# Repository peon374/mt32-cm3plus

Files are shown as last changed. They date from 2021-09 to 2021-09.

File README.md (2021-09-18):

# mt32-cm3plus
This is a CM3+ version of the MT32Pi hardware. All layout is done in Kicad and I will create release files with everything needed to get a run of boards done and half assembled with jlcpcb.

This project is a hardware implementation designed to work with [MT32-Pi](https://github.com/dwhinham/mt32-pi)

_THIS IS A WORK IN PROGRESS AND ISN'T COMPLETE_

You should not build this till there are is a working release. The convention I will be using is to call something a release candidate (RC) till I know everything I have added works and I have reasonable documentation. If you do not see reasonable documentation, either contribute doco, ideas or bugs you can see in what I have done. The plan is to have everything that can be populated out of JLCPCB basic parts on the underside so that a lot of the fiddly bits are already done. The SODIMM connector for the CM3+ is not simple if you don't have a good iron and good flux. Both can be found on Aliexpress with a bit of research but flux is more of a gamble.

I plan to continue improving the device, so if you have any ideas put them in.

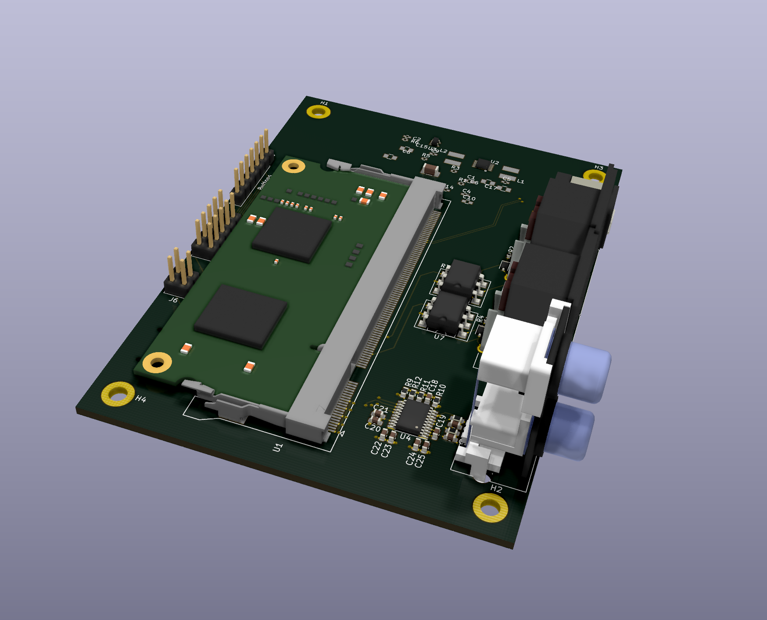
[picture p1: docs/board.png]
Board


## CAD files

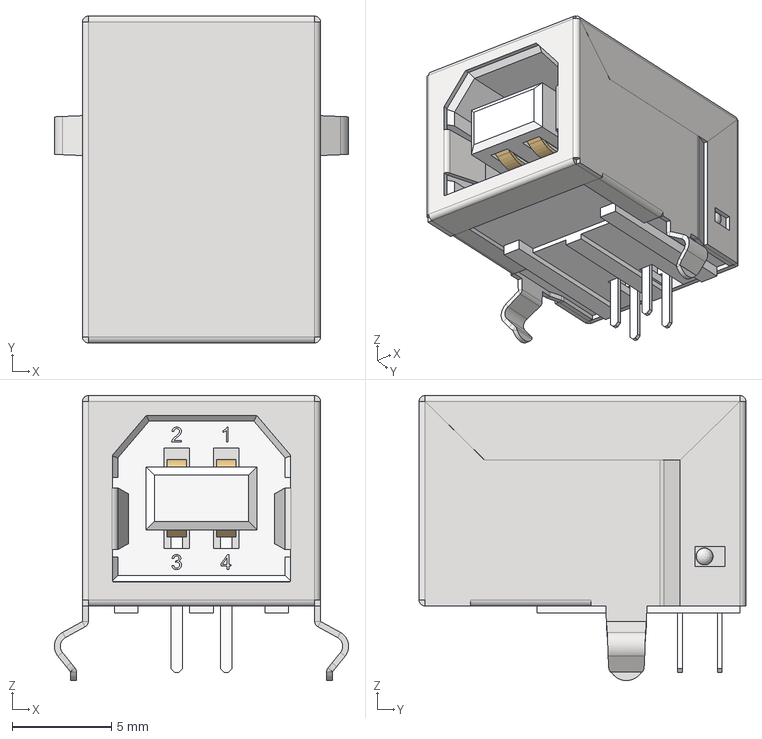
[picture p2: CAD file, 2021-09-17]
hardware/step/USB 2.0 Type B Connector Right Angle (Würth 61400416121).stp
14.8 x 16.5 x 14.4 mm

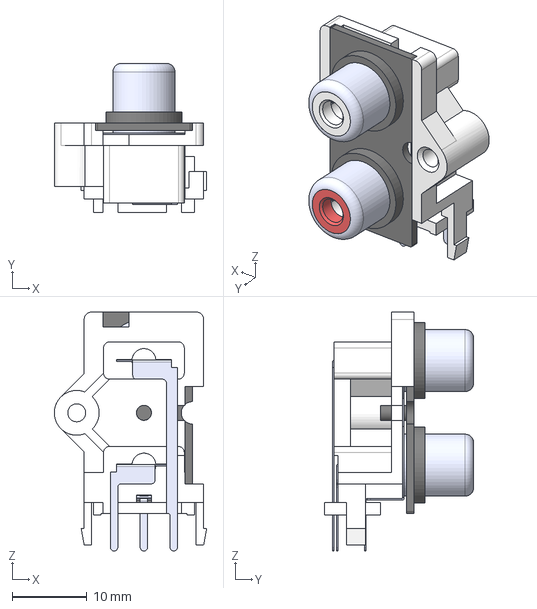
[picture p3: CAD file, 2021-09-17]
hardware/step/RS-209.step
20.4 x 20.0 x 32.0 mm

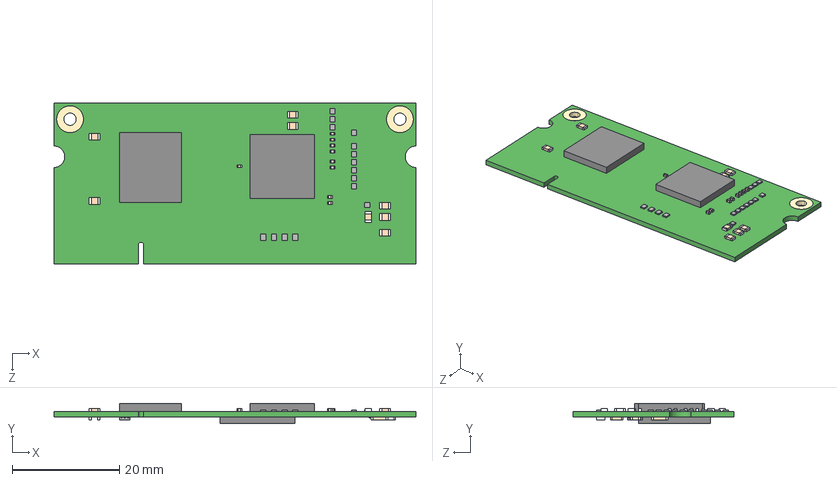
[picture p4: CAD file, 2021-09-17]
hardware/step/RASPBERRYPI-CM3--3DModel-STEP-56544.STEP
67.6 x 3.80 x 30.0 mm

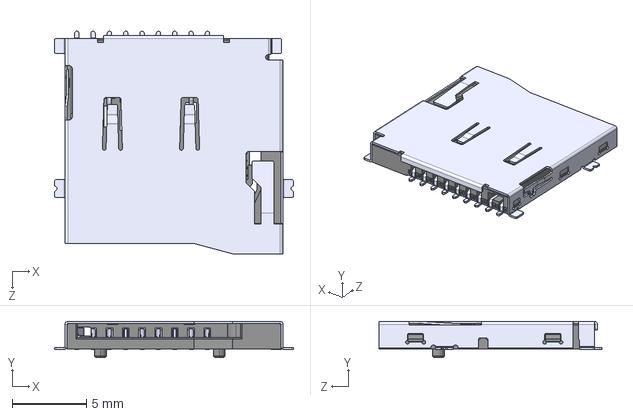
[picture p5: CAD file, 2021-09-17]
hardware/step/ST-TF-003A--3DModel-STEP-56544.STEP
16.1 x 2.45 x 15.0 mm

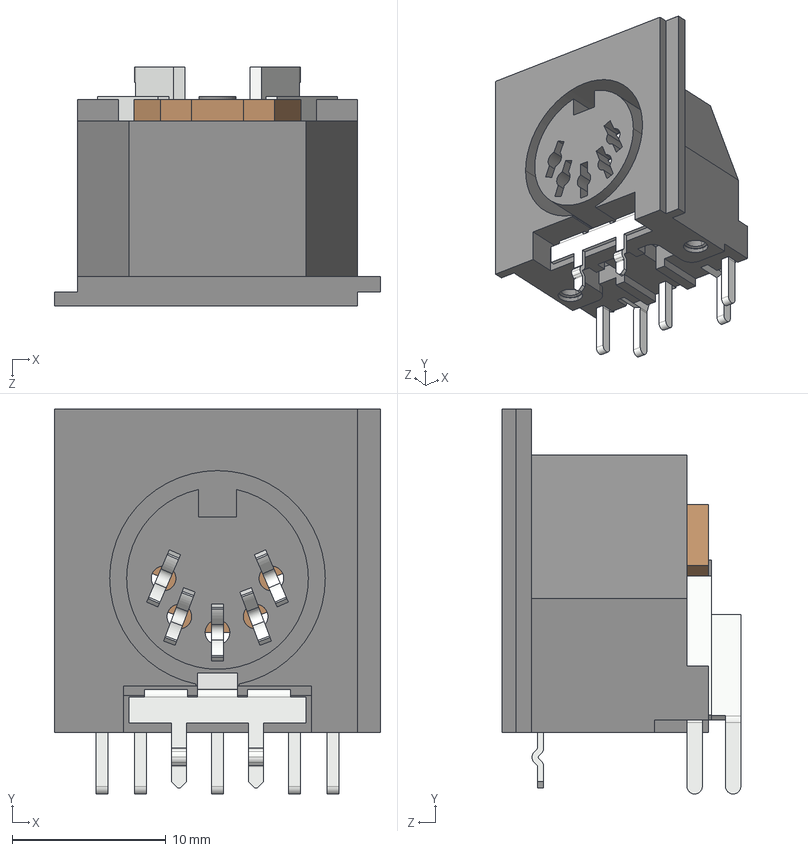
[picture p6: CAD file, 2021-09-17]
hardware/step/DIN5_PCB_DELTRON_671-0500.STEP
21.2 x 25.0 x 15.5 mm
DIN5_PCB_DELTRON_BODY
DIN5_PCB_DELTRON_PIN2
DIN5_PCB_DELTRON_PIN5
DIN5_PCB_DELTRON_PIN3
DIN5_PCB_DELTRON_PIN4
DIN5_PCB_DELTRON_PIN1
DIN5_PCB_DELTRON_FIX
DIN5_PCB_DELTRON_SHIELD

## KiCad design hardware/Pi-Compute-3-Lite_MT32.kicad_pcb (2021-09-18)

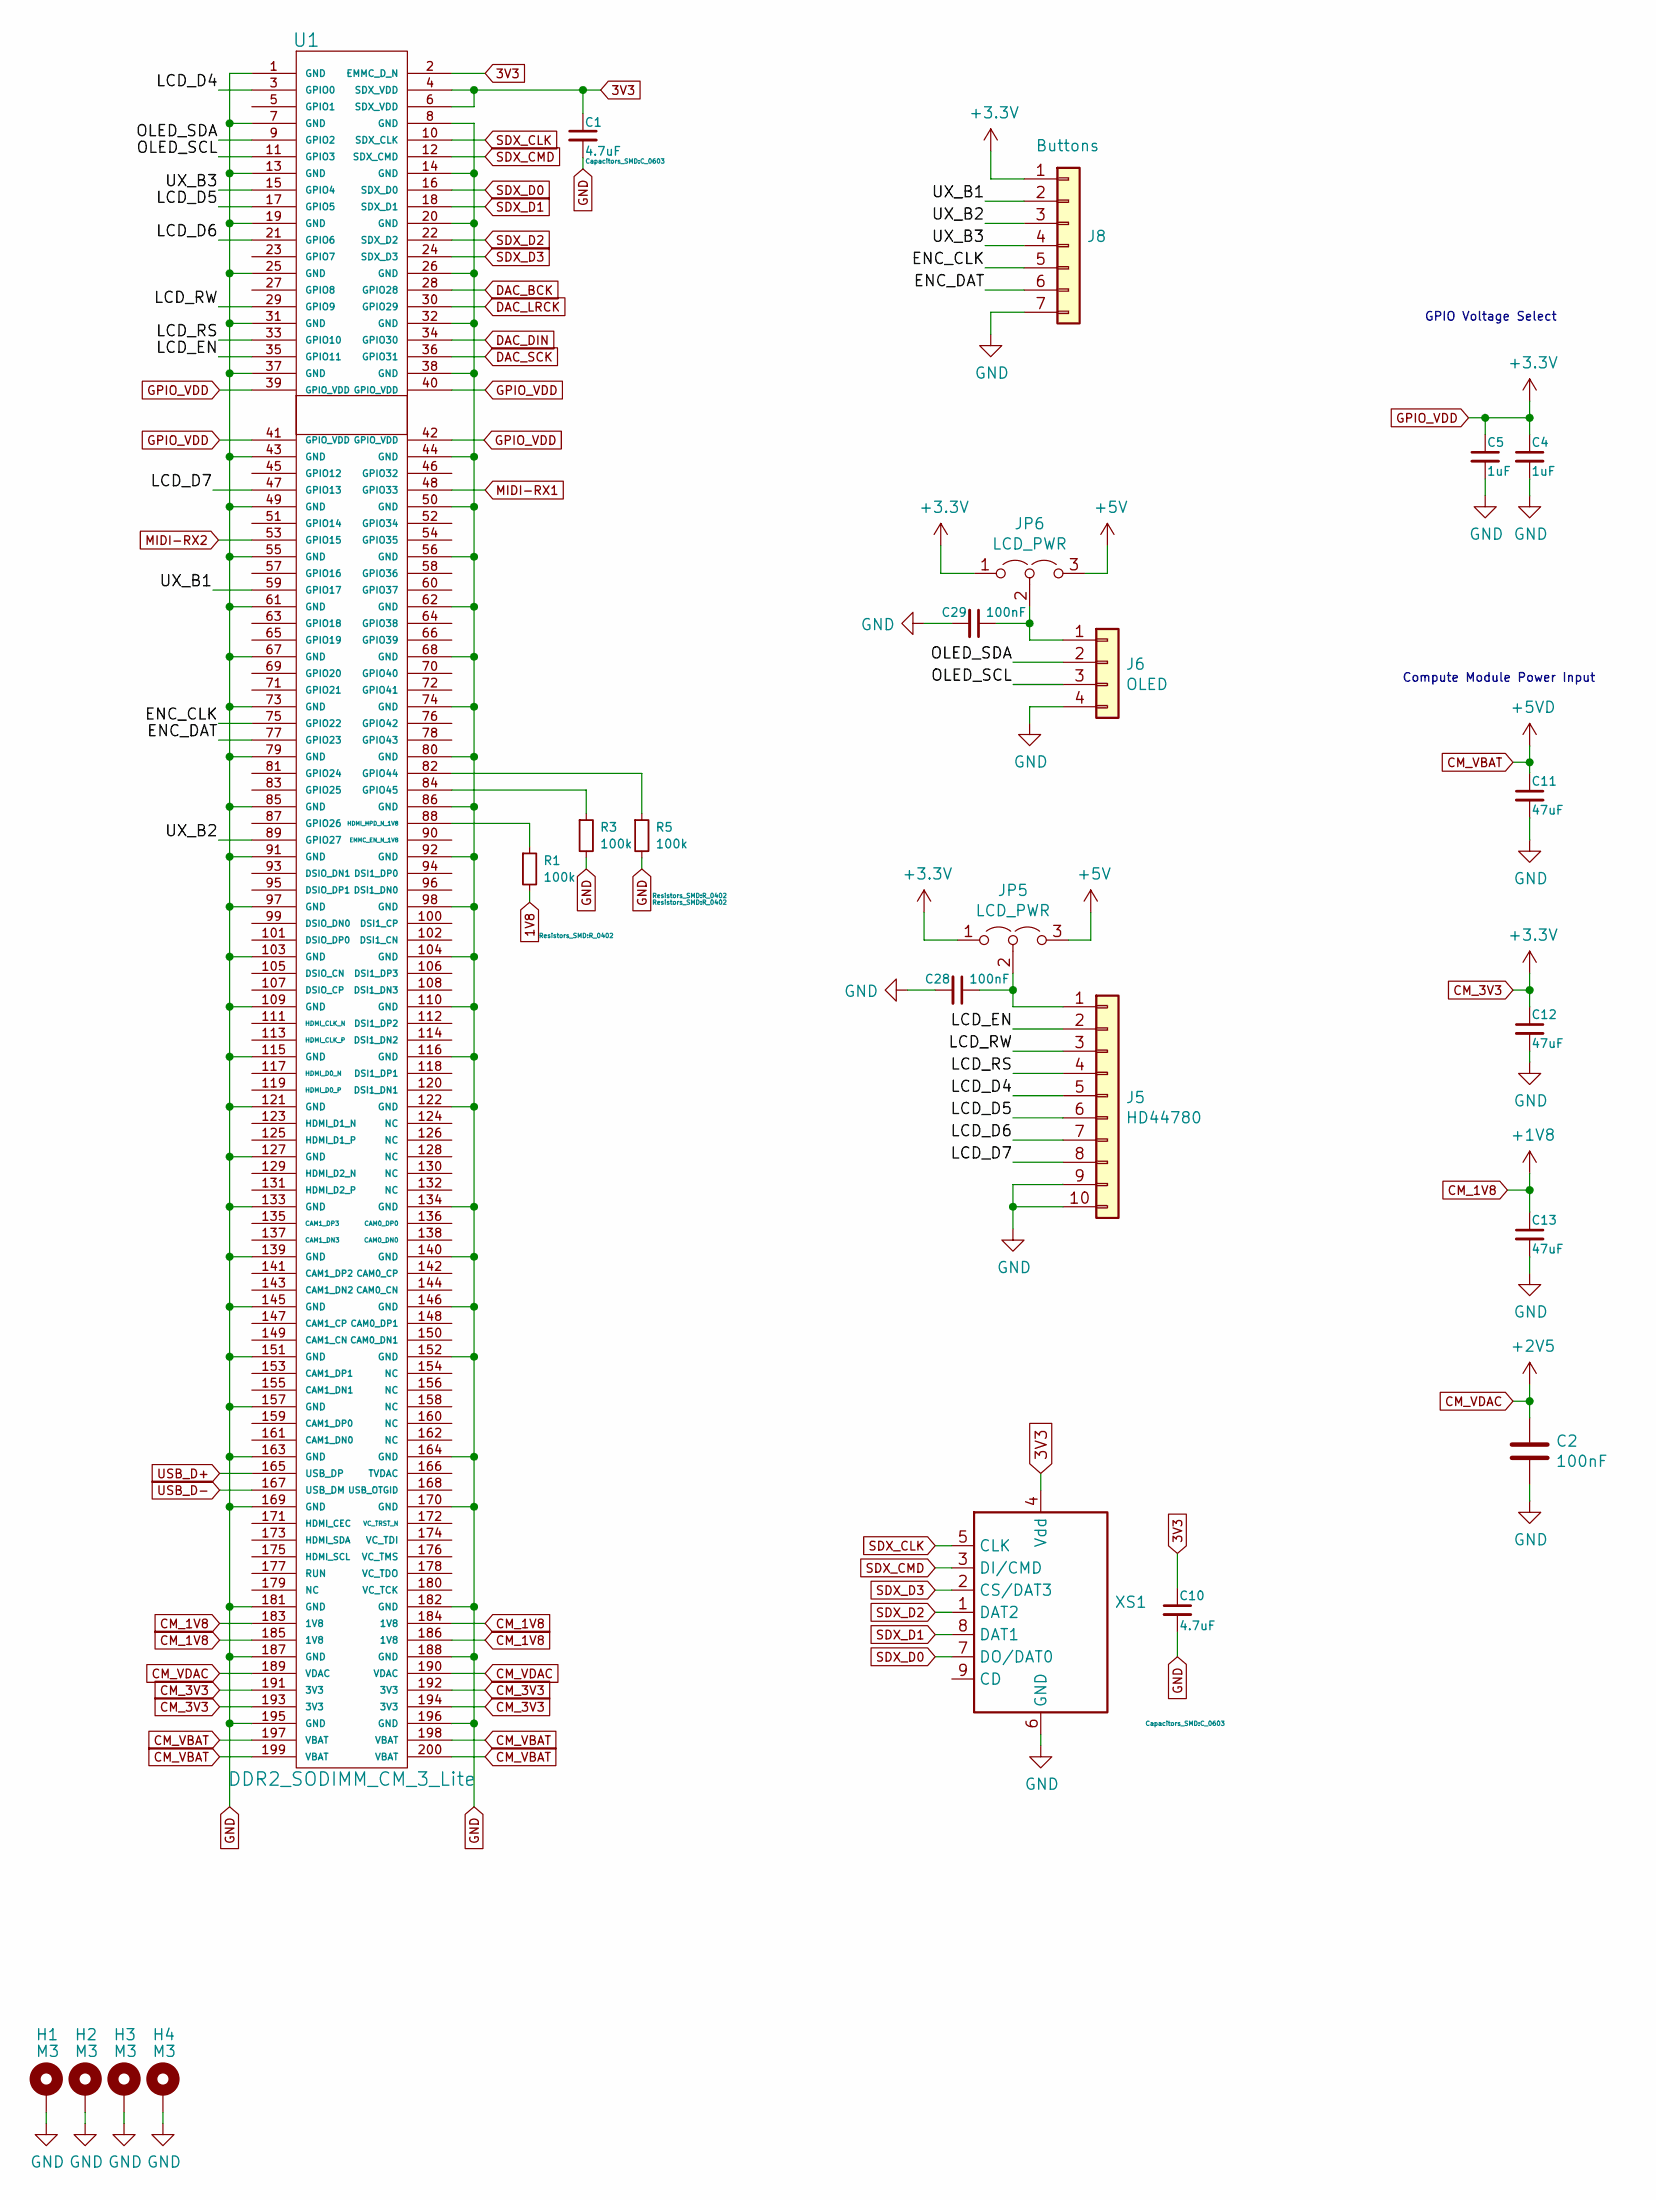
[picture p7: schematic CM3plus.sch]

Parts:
C1, C10: 4.7uF; C_0603
C2: 100nF; C_0402_1005Metric
C4, C5: 1uF; C_0402_1005Metric
C11, C12, C13: 47uF; C_1206_3216Metric
C28, C29: 100nF; C_0402
H1, H2, H3, H4: M3; MountingHole_3.2mm_M3_DIN965_Pad
J5: HD44780; PinHeader_2x05_P2.54mm_Vertical
J6: OLED; PinHeader_2x02_P2.54mm_Vertical
J8: Buttons; PinHeader_1x07_P2.54mm_Vertical
JP5, JP6: LCD_PWR; SolderJumper-3_P1.3mm_Open_Pad1.0x1.5mm
R1, R3, R5: 100k; R_0402
U1: DDR2_SODIMM_CM_3_Lite; Socket_SODIMM_DDR2
XS1: SD_ebay-uSD-push_push_SMD; Conn_uSDcard

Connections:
3V3: C1.1, C10.1, U1.2 (EMMC_D_N), U1.4 (SDX_VDD), U1.6 (SDX_VDD), XS1.4 (Vdd); also elsewhere on the board
+5V: JP5.3 (B), JP6.3 (B)
/Raspberry PI CM3+/ENC_CLK: J8.5, U1.75 (GPIO22)
/Raspberry PI CM3+/ENC_DAT: J8.6, U1.77 (GPIO23)
/Raspberry PI CM3+/LCD_D4: J5.5, U1.3 (GPIO0)
/Raspberry PI CM3+/LCD_D5: J5.6, U1.17 (GPIO5)
/Raspberry PI CM3+/LCD_D6: J5.7, U1.21 (GPIO6)
/Raspberry PI CM3+/LCD_D7: J5.8, U1.47 (GPIO13)
/Raspberry PI CM3+/LCD_EN: J5.2, U1.35 (GPIO11)
/Raspberry PI CM3+/LCD_RS: J5.4, U1.33 (GPIO10)
/Raspberry PI CM3+/LCD_RW: J5.3, U1.29 (GPIO9)
/Raspberry PI CM3+/OLED_SCL: J6.3, U1.11 (GPIO3)
/Raspberry PI CM3+/OLED_SDA: J6.2, U1.9 (GPIO2)
/Raspberry PI CM3+/UX_B1: J8.2, U1.59 (GPIO17)
/Raspberry PI CM3+/UX_B2: J8.3, U1.89 (GPIO27)
/Raspberry PI CM3+/UX_B3: J8.4, U1.15 (GPIO4)
CM_1V8: C13.1, U1.183 (1V8), U1.184 (1V8), U1.185 (1V8), U1.186 (1V8); also elsewhere on the board
CM_3V3: C4.1, C5.1, C12.1, J8.1, JP5.1 (A), JP6.1 (A), U1.39 (GPIO_VDD), U1.40 (GPIO_VDD), U1.41 (GPIO_VDD), U1.42 (GPIO_VDD), U1.191 (3V3), U1.192 (3V3), U1.193 (3V3), U1.194 (3V3); also elsewhere on the board
CM_VBAT: C11.1, U1.197 (VBAT), U1.198 (VBAT), U1.199 (VBAT), U1.200 (VBAT); also elsewhere on the board
CM_VDAC: C2.1, U1.189 (VDAC), U1.190 (VDAC)
DAC_BCK: U1.28 (GPIO28); also elsewhere on the board
DAC_DIN: U1.34 (GPIO30); also elsewhere on the board
DAC_LRCK: U1.30 (GPIO29); also elsewhere on the board
DAC_SCK: U1.36 (GPIO31); also elsewhere on the board
GND: C1.2, C2.2, C4.2, C5.2, C10.2, C11.2, C12.2, C13.2, C28.2, C29.2, H1.1, H2.1, H3.1, H4.1, J5.9, J5.10, J6.4, J8.7, R3.2, R5.2, U1.1 (GND), U1.7 (GND), U1.8 (GND), U1.13 (GND), U1.14 (GND), U1.19 (GND), U1.20 (GND), U1.25 (GND), U1.26 (GND), U1.31 (GND), U1.32 (GND), U1.37 (GND), U1.38 (GND), U1.43 (GND), U1.44 (GND), U1.49 (GND), U1.50 (GND), U1.55 (GND), U1.56 (GND), U1.61 (GND), U1.62 (GND), U1.67 (GND), U1.68 (GND), U1.73 (GND), U1.74 (GND), U1.79 (GND), U1.80 (GND), U1.85 (GND), U1.86 (GND), U1.91 (GND), U1.92 (GND), U1.97 (GND), U1.98 (GND), U1.103 (GND), U1.104 (GND), U1.109 (GND), U1.110 (GND), U1.115 (GND), U1.116 (GND), U1.121 (GND), U1.122 (GND), U1.127 (GND), U1.133 (GND), U1.134 (GND), U1.139 (GND), U1.140 (GND), U1.145 (GND), U1.146 (GND), U1.151 (GND), U1.152 (GND), U1.157 (GND), U1.163 (GND), U1.164 (GND), U1.169 (GND), U1.170 (GND), U1.181 (GND), U1.182 (GND), U1.187 (GND), U1.188 (GND), U1.195 (GND), U1.196 (GND), XS1.6 (GND); also elsewhere on the board
MIDI-RX1: U1.48 (GPIO33); also elsewhere on the board
MIDI-RX2: U1.53 (GPIO15); also elsewhere on the board
unnamed: C28.1, J5.1, JP5.2 (C)
unnamed: C29.1, J6.1, JP6.2 (C)
unnamed: R1.1, U1.88 (HDMI_HPD_N_1V8)
unnamed: R3.1, U1.84 (GPIO45)
unnamed: R5.1, U1.82 (GPIO44)
SDX_CLK: U1.10 (SDX_CLK), XS1.5 (CLK)
SDX_CMD: U1.12 (SDX_CMD), XS1.3 (DI/CMD)
SDX_D0: U1.16 (SDX_D0), XS1.7 (DO/DAT0)
SDX_D1: U1.18 (SDX_D1), XS1.8 (DAT1)
SDX_D2: U1.22 (SDX_D2), XS1.1 (DAT2)
SDX_D3: U1.24 (SDX_D3), XS1.2 (CS/DAT3)
USB_D+: U1.165 (USB_DP); also elsewhere on the board
USB_D-: U1.167 (USB_DM); also elsewhere on the board

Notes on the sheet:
GPIO Voltage Select
Compute Module Power Input

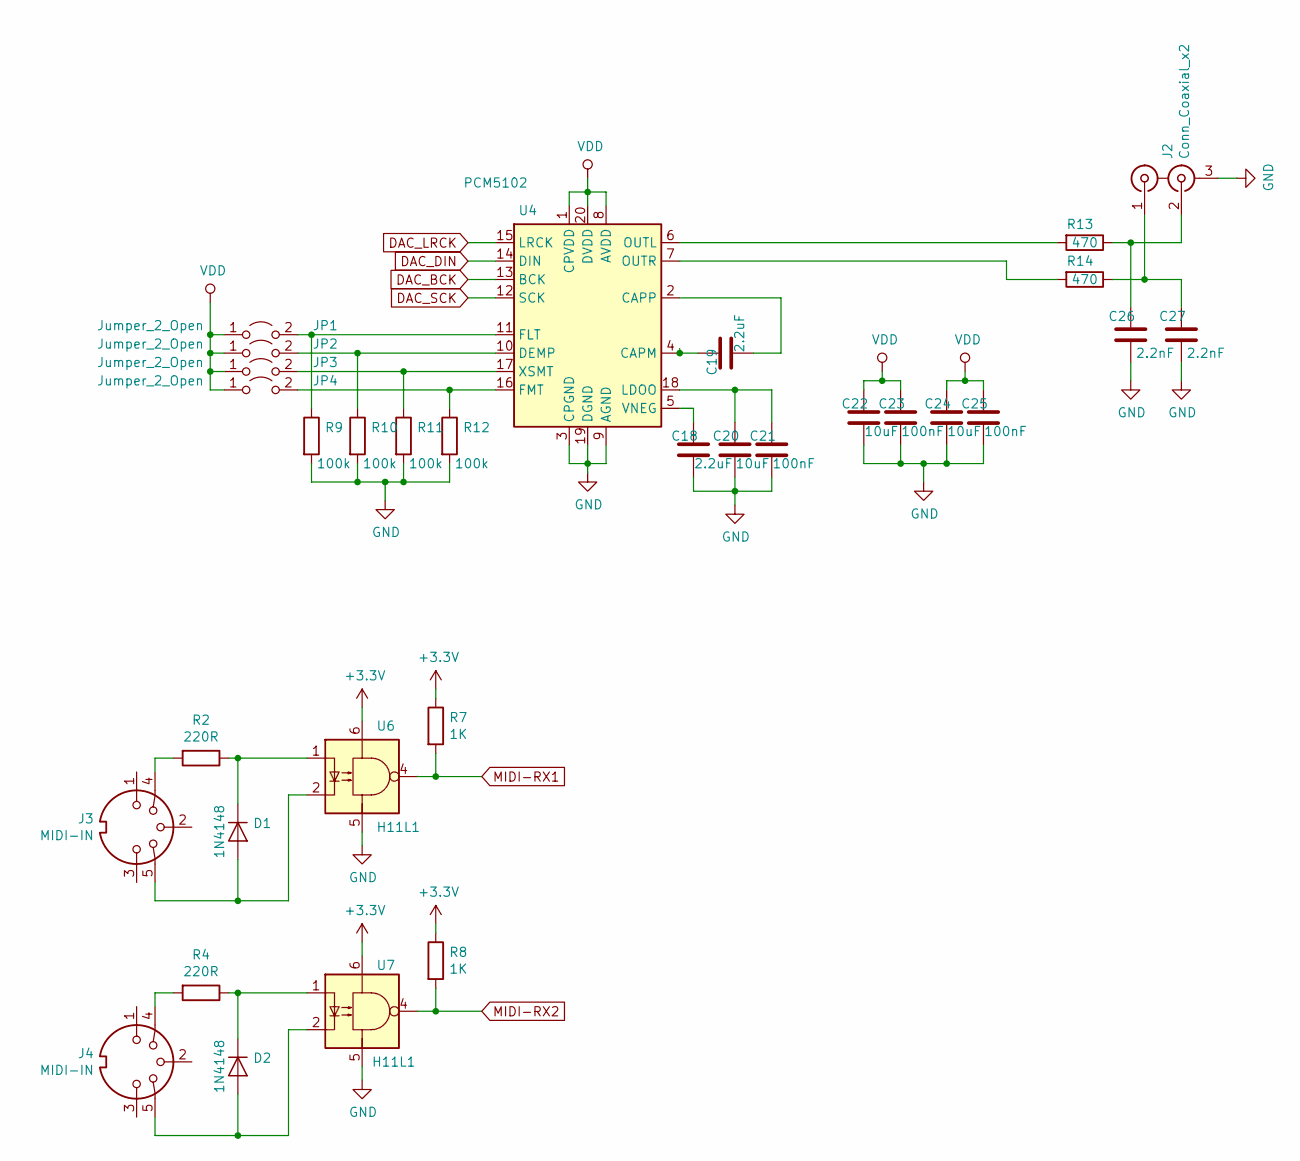
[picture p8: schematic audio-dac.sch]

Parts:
C18, C19: 2.2uF; C_0603_1608Metric
C20, C22, C24: 10uF; C_0603_1608Metric
C21, C23, C25: 100nF; C_0603_1608Metric
C26, C27: 2.2nF; C_0603_1608Metric
D1, D2: 1N4148; D_SOD-323F; LCSC C2128
J2: Conn_Coaxial_x2; DUALRCA
J3, J4: MIDI-IN; SWITCHCRAFT_57PC5FS
JP1, JP2, JP3, JP4: Jumper_2_Open; SolderJumper-2_P1.3mm_Open_Pad1.0x1.5mm
R2, R4: 220R; R_0402_1005Metric; LCSC C25091
R7, R8: 1K; R_0402_1005Metric; LCSC C11702
R9, R10, R11, R12: 100k; R_0603_1608Metric
R13, R14: 470; R_0603_1608Metric
U4: PCM5102; TSSOP-20_4.4x6.5mm_P0.65mm
U6, U7: H11L1; DIP-6_W7.62mm_SMDSocket_SmallPads

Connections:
CM_3V3: R7.1, R8.1, U6.6, U7.6; also elsewhere on the board
DAC_BCK: U4.13 (BCK); also elsewhere on the board
DAC_DIN: U4.14 (DIN); also elsewhere on the board
DAC_LRCK: U4.15 (LRCK); also elsewhere on the board
DAC_SCK: U4.12 (SCK); also elsewhere on the board
GND: C18.2, C20.2, C21.2, C22.2, C23.2, C24.2, C25.2, C26.2, C27.2, J2.3 (EXT), R9.2, R10.2, R11.2, R12.2, U4.3 (CPGND), U4.9 (AGND), U4.19 (DGND), U6.5, U7.5; also elsewhere on the board
MIDI-RX1: R7.2, U6.4; also elsewhere on the board
MIDI-RX2: R8.2, U7.4; also elsewhere on the board
unnamed: C18.1, U4.5 (VNEG)
unnamed: C19.1, U4.4 (CAPM)
unnamed: C19.2, U4.2 (CAPP)
unnamed: C20.1, C21.1, U4.18 (LDOO)
unnamed: C26.1, J2.2 (IN2), R13.1
unnamed: C27.1, J2.1 (IN1), R14.1
unnamed: D1.1 (K), R2.1, U6.1
unnamed: D1.2 (A), J3.5, U6.2
unnamed: D2.1 (K), R4.1, U7.1
unnamed: D2.2 (A), J4.5, U7.2
unnamed: J3.4, R2.2
unnamed: J4.4, R4.2
unnamed: JP1.2 (B), R9.1, U4.11 (FLT)
unnamed: JP2.2 (B), R10.1, U4.10 (DEMP)
unnamed: JP3.2 (B), R11.1, U4.17 (XSMT)
unnamed: JP4.2 (B), R12.1, U4.16 (FMT)
unnamed: R13.2, U4.6 (OUTL)
unnamed: R14.2, U4.7 (OUTR)
VDD: C22.1, C23.1, C24.1, C25.1, JP1.1 (A), JP2.1 (A), JP3.1 (A), JP4.1 (A), U4.1 (CPVDD), U4.8 (AVDD), U4.20 (DVDD)

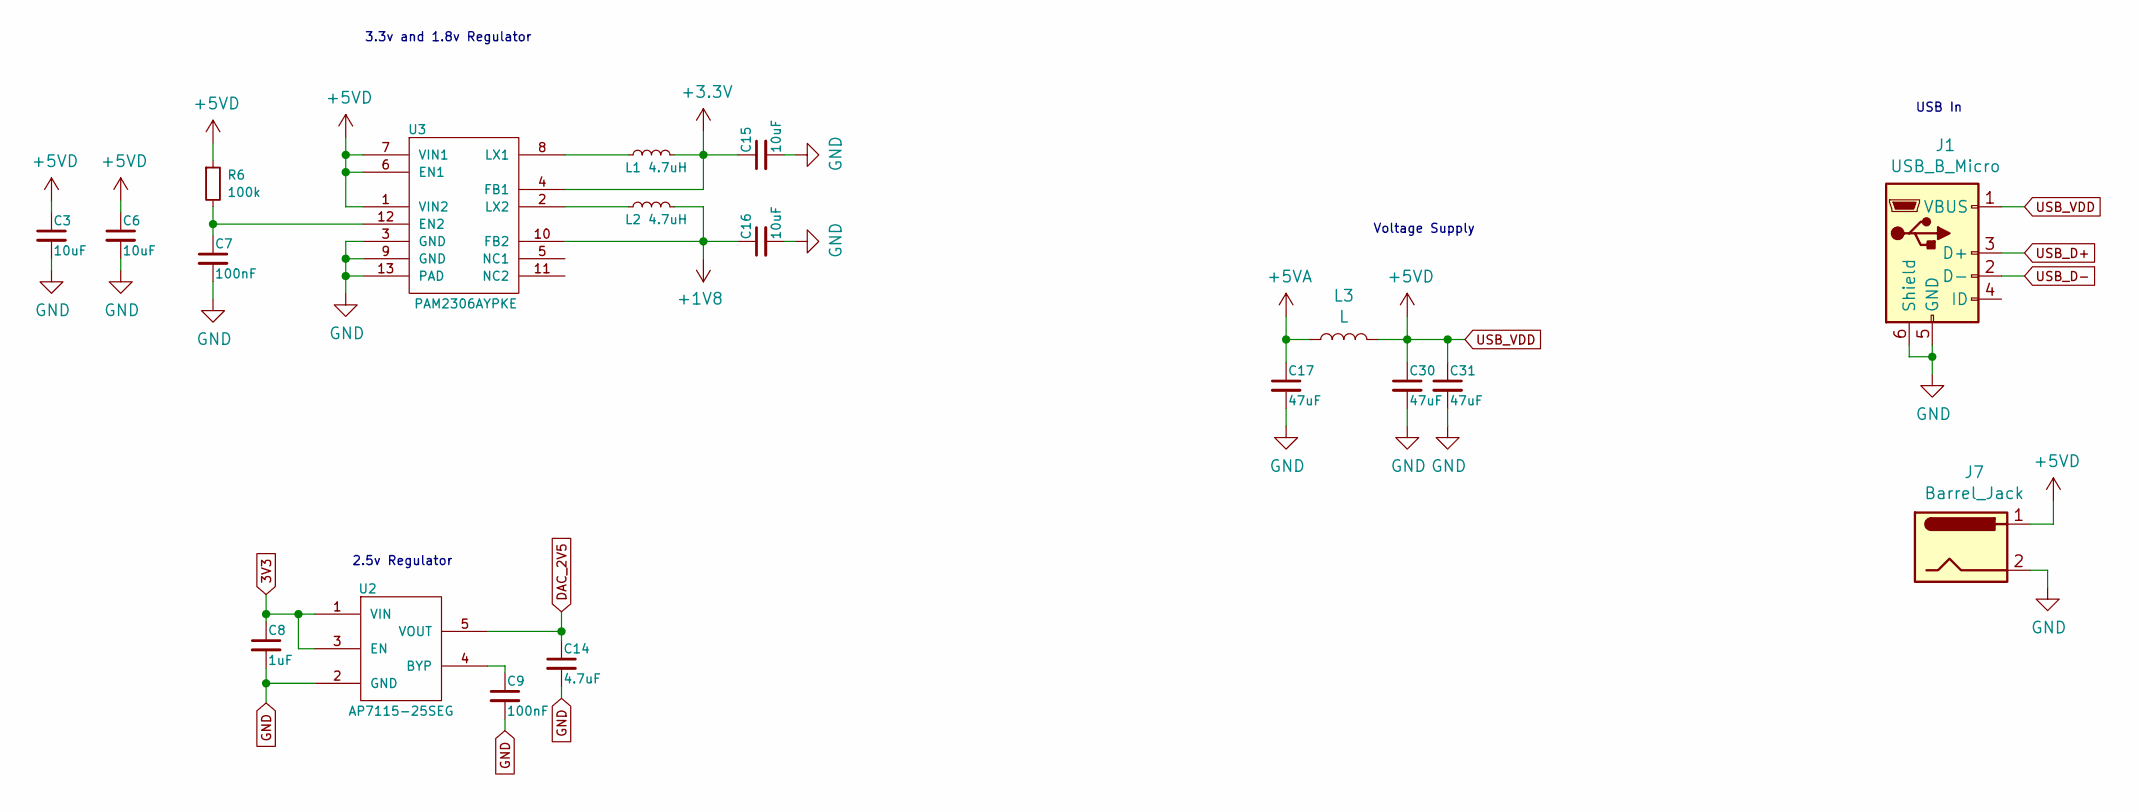
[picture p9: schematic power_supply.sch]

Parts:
C3, C6, C15, C16: 10uF; C_0805_2012Metric; LCSC C15850
C7, C9: 100nF; C_0402_1005Metric; LCSC C1525
C8: 1uF; C_0402_1005Metric; LCSC C52923
C14: 4.7uF; C_0402_1005Metric; LCSC C23733
C17, C30, C31: 47uF; C_1206_3216Metric; LCSC C96123
J1: USB_B_Micro; USB_Micro-B_Amphenol_10103594-0001LF_Horizontal
J7: Barrel_Jack; BarrelJack_Horizontal
L1, L2: 4.7uH; L_Bourns-SRN4018; LCSC C408337
L3: L
R6: 100k; R_0402_1005Metric; LCSC C25086
U2: AP7115-25SEG; AP7115-25SEG-7; LCSC C780771
U3: PAM2306AYPKE; LCSC C508236

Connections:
3V3: C8.1, U2.1 (VIN), U2.3 (EN); also elsewhere on the board
CM_1V8: C16.1, L2.2, U3.10 (FB2); also elsewhere on the board
CM_3V3: C15.1, L1.2, U3.4 (FB1); also elsewhere on the board
CM_VBAT: C3.1, C6.1, C30.1, C31.1, J1.1 (VBUS), J7.1, L3.2, R6.1, U3.1 (VIN2), U3.6 (EN1), U3.7 (VIN1); also elsewhere on the board
GND: C3.2, C6.2, C7.2, C8.2, C9.2, C14.2, C15.2, C16.2, C17.2, C30.2, C31.2, J1.5 (GND), J1.6 (Shield), J7.2, U2.2 (GND), U3.3 (GND), U3.9 (GND), U3.13 (PAD); also elsewhere on the board
unnamed: C7.1, R6.2, U3.12 (EN2)
unnamed: C17.1, L3.1
unnamed: C9.1, U2.4 (BYP)
unnamed: C14.1, U2.5 (VOUT)
unnamed: L2.1, U3.2 (LX2)
unnamed: L1.1, U3.8 (LX1)
USB_D+: J1.3 (D+); also elsewhere on the board
USB_D-: J1.2 (D-); also elsewhere on the board

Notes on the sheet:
3.3v and 1.8v Regulator
2.5v Regulator
Voltage Supply
USB In

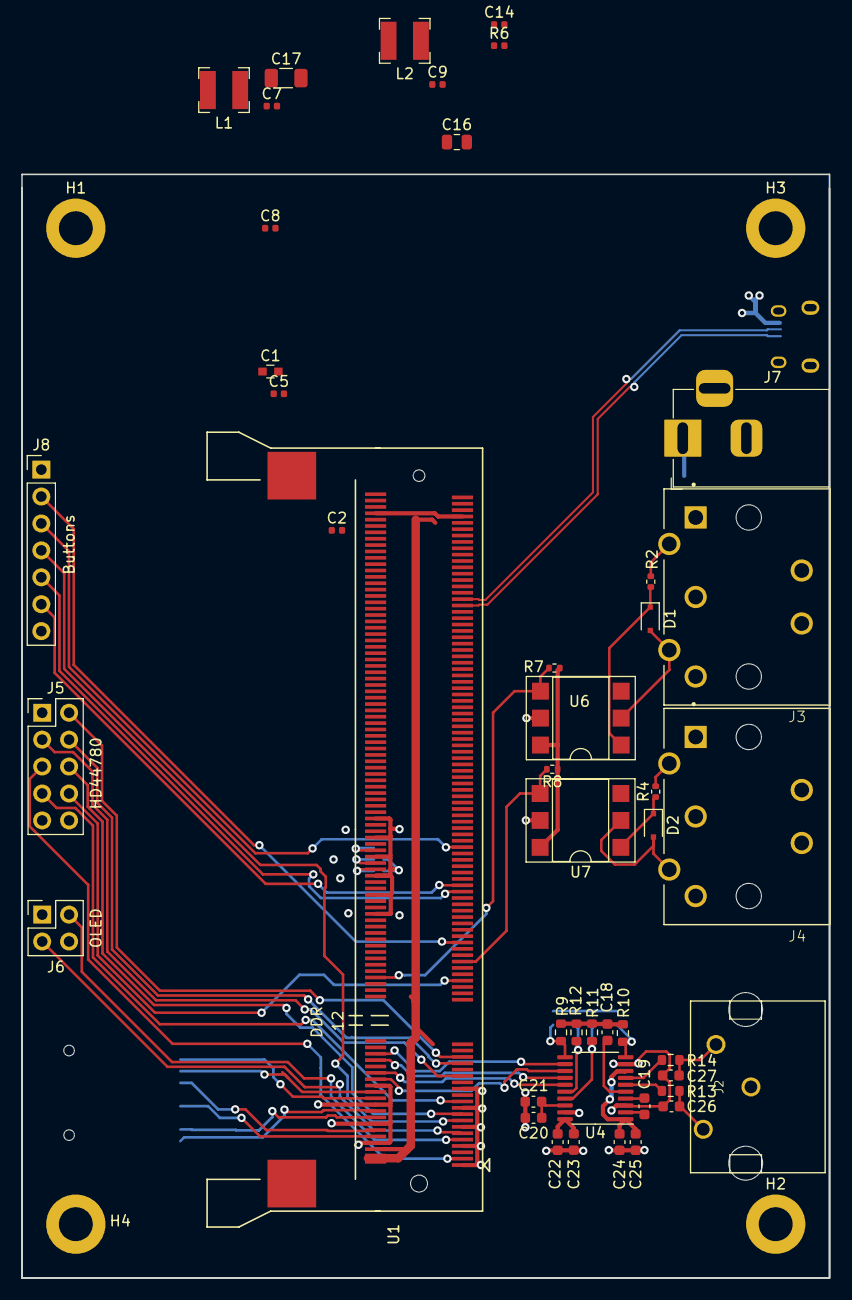
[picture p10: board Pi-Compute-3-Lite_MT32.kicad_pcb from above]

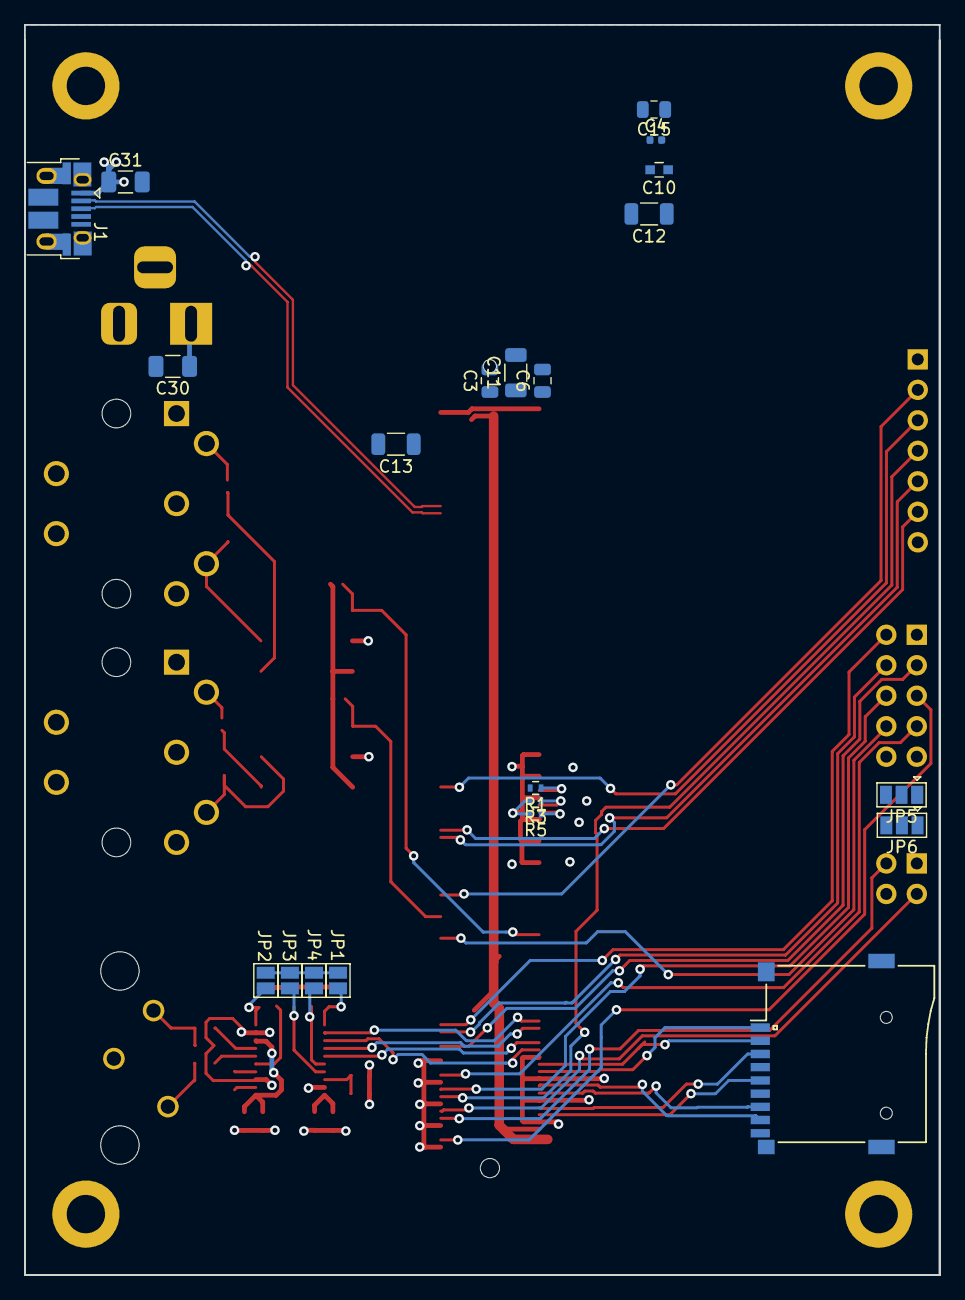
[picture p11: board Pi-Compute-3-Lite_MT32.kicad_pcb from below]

Board: 2 copper layers, 76.2 x 104.1 mm, 70 parts (21 on the bottom side), 60 nets.

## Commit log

2021-09-17 Added start
    [CM3plus.sch, DIN5_PCB_DELTRON_671-0500.STEP, Pi-Compute-3-Lite_MT32.kicad_pcb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]
2021-09-18 Cleaning up the power section
    [CM3plus.sch, Pi-Compute-3-Lite_MT32.kicad_pcb, Pi-Compute-3-Lite_MT32.sch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]
